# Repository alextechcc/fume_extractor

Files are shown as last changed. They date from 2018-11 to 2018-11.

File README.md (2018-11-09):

# Fume Extractor
A 3d printable fume extractor with a 555 PWM fan controller made in KiCad

- Currently I use a more powerful fan without PWM control, and have used the PWM signal to dim a 10W led driver

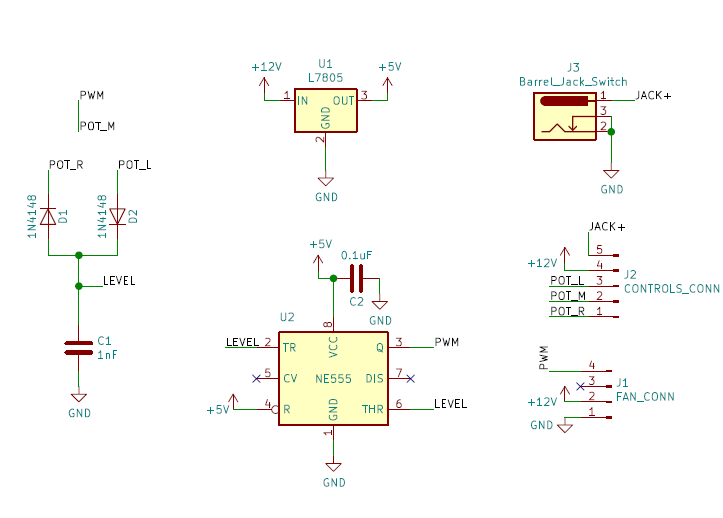
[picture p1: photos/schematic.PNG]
Board

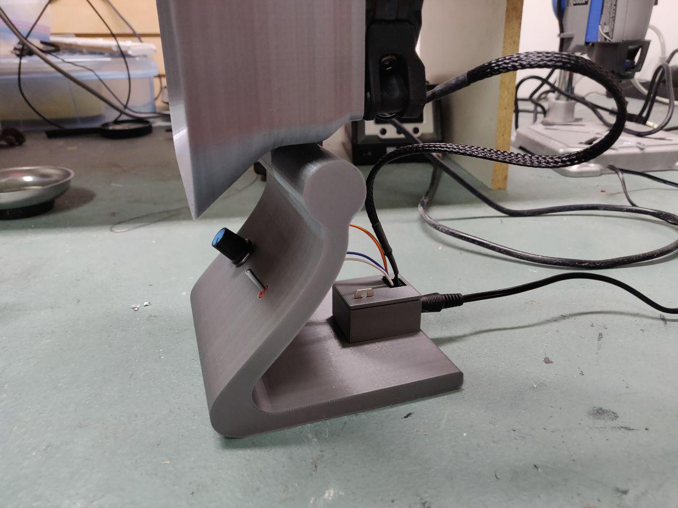
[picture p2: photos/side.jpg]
Side

# Sources
- [Solder Fume Extractor 120 mm by koensmelt](https://www.thingiverse.com/thing:1436781)
- [Customizable Fan Grill Cover by mightynozzle](https://www.thingiverse.com/thing:2802474)

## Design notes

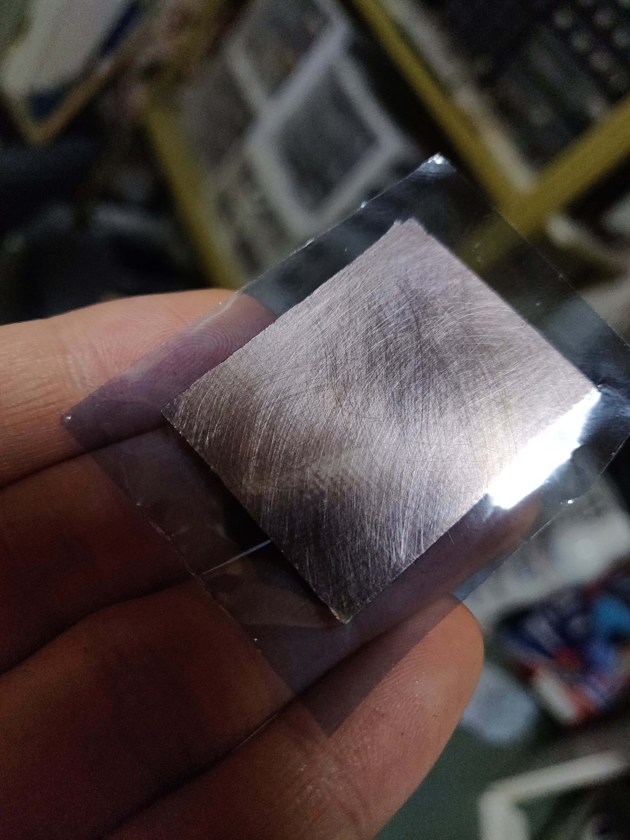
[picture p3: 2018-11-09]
photos/laminated.jpg

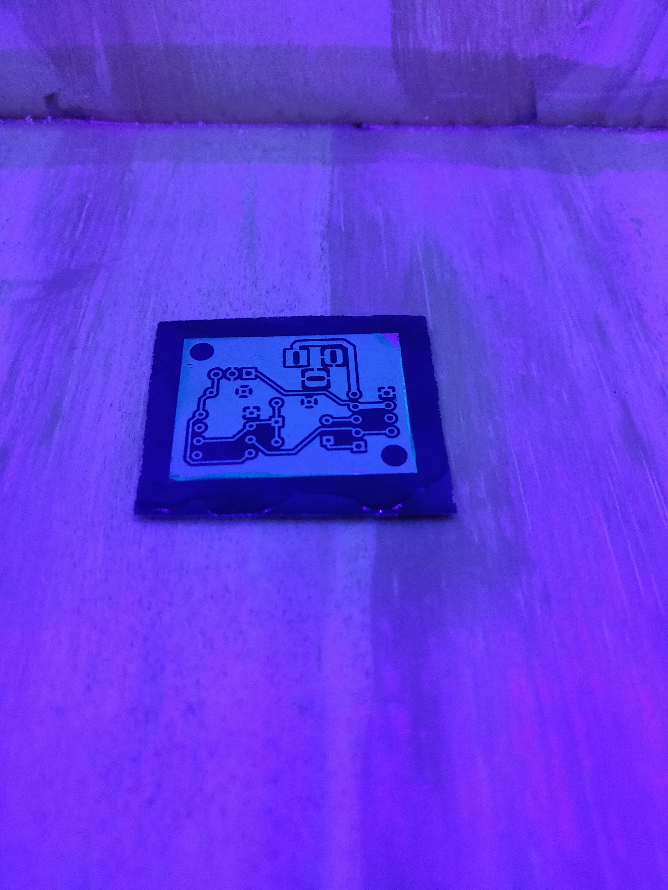
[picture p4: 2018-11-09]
photos/exposing.jpg

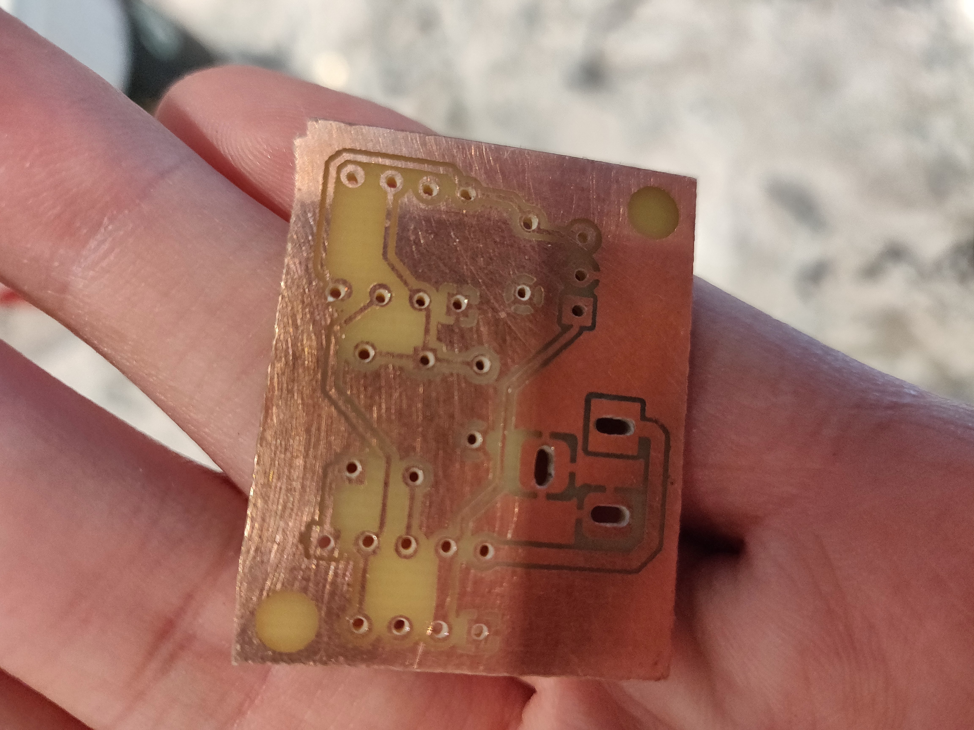
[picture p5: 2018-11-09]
photos/etched_drilled.jpg

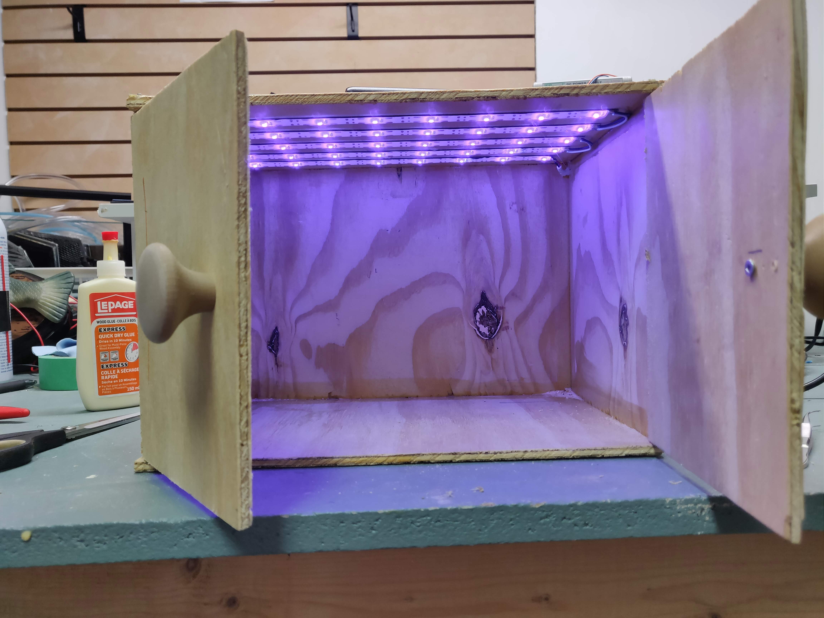
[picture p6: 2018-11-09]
photos/expose_box.jpg

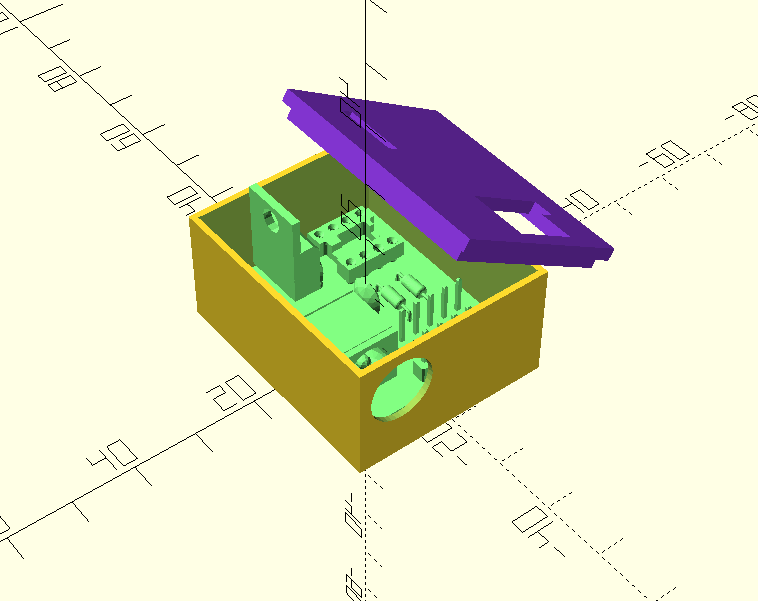
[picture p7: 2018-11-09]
photos/openscad.PNG

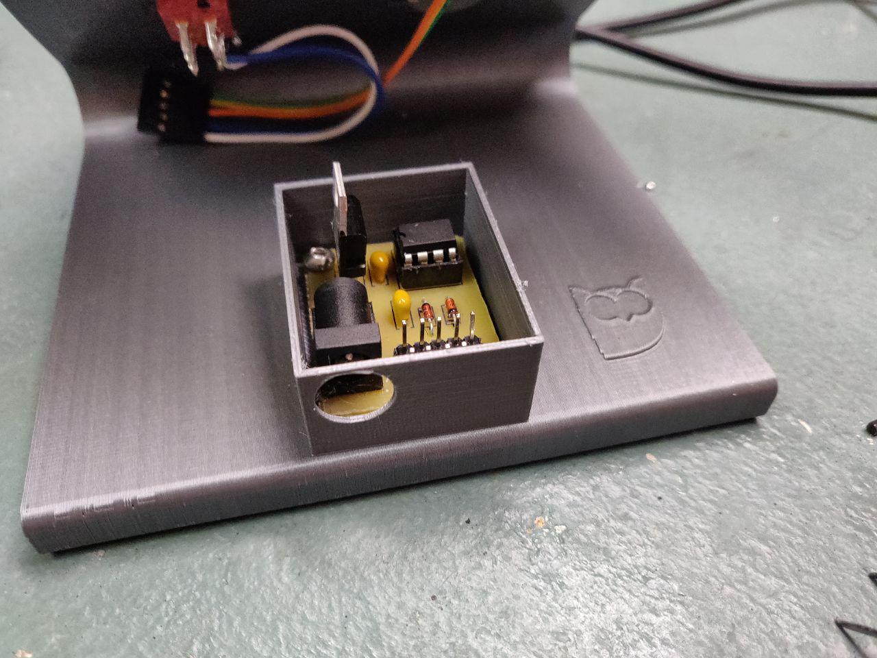
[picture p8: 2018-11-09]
photos/attached.jpg

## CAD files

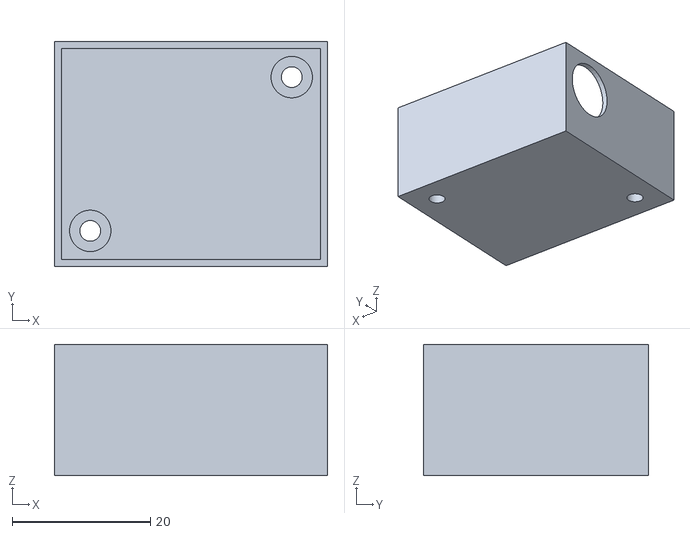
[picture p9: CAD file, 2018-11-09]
exports/case.stl
39.6 x 32.6 x 19.0

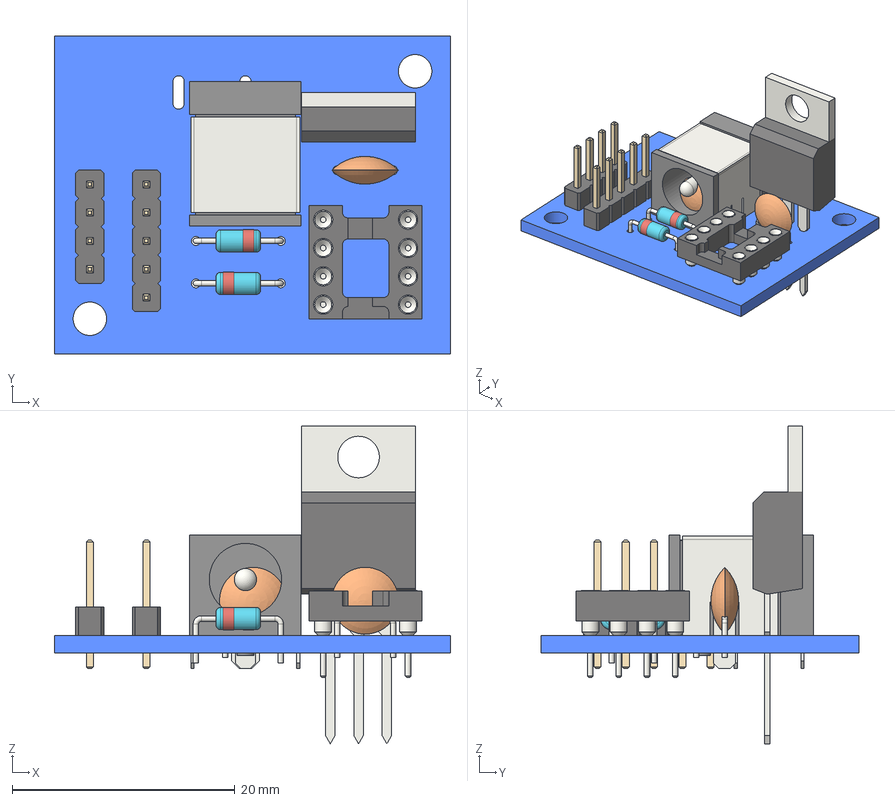
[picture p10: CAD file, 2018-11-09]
freecad/fume_extractor_pcb3.step
35.6 x 28.6 x 28.5 mm

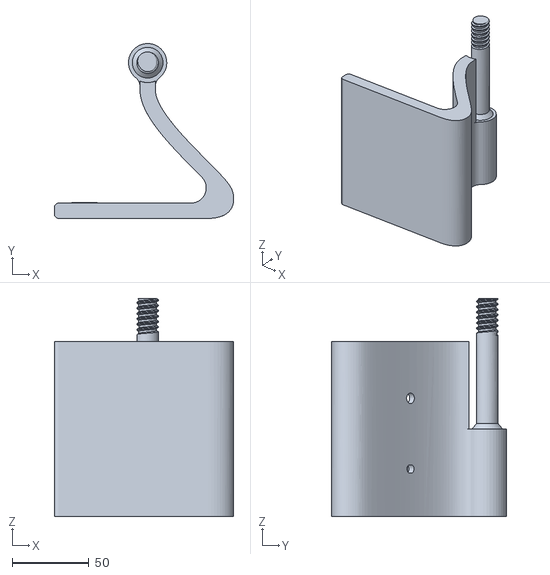
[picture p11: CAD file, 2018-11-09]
models/base_mod.stl
116.9 x 113.9 x 142.0

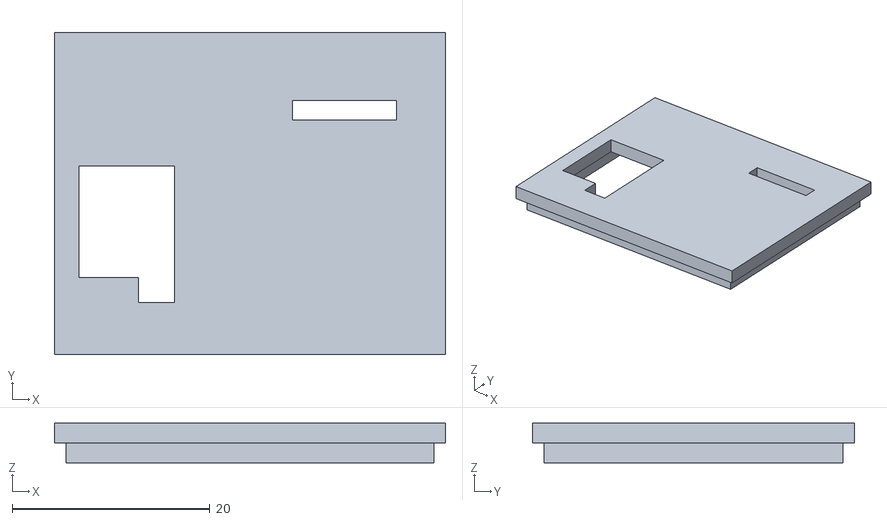
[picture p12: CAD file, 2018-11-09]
exports/lid.stl
39.6 x 32.6 x 4.00

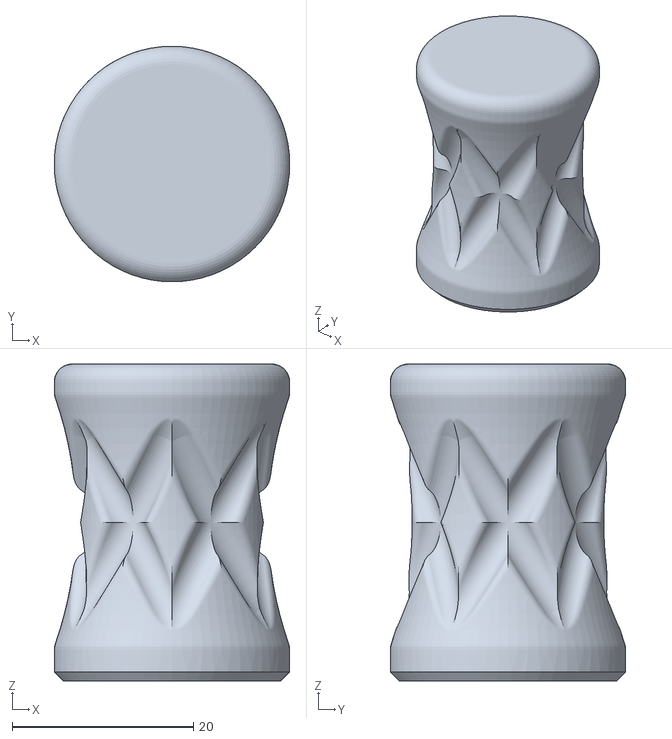
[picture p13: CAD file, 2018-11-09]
models/fume_extractor_knob.STL
26.0 x 26.0 x 35.0

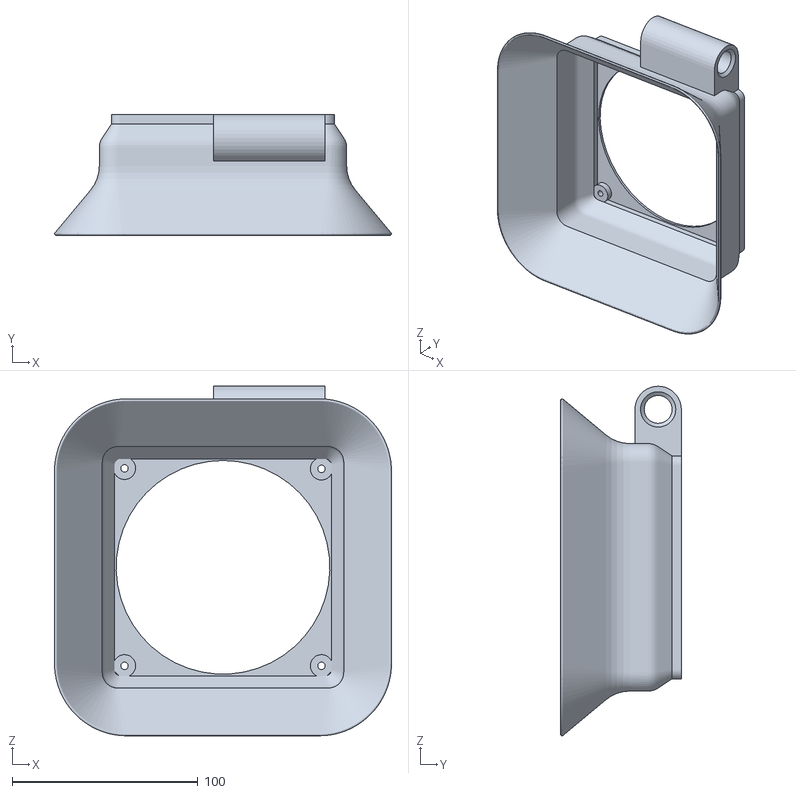
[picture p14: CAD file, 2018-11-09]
models/fume_extractor_head.STL
181.4 x 65.0 x 188.2

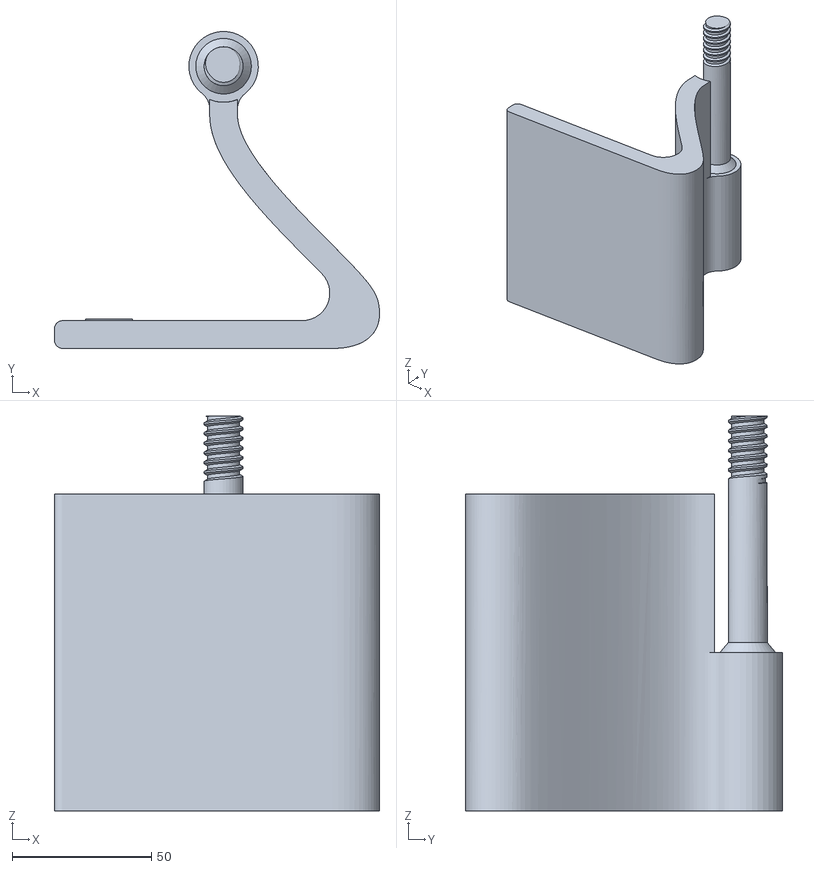
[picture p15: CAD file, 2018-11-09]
models/fume_extractor_foot.STL
116.9 x 113.9 x 142.0

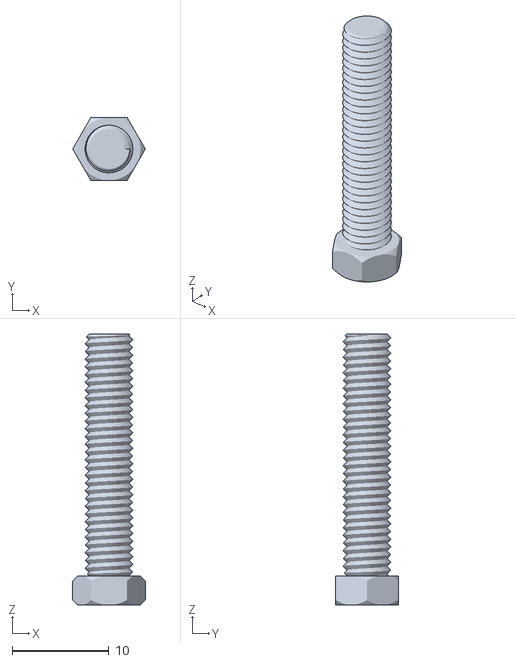
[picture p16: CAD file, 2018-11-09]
models/Nut_Job.stl
7.51 x 6.50 x 28.0

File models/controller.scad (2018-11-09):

use <../../util.scad>

connector_r = 7;
thickness = 2;

header_w = 12.74;
header_d = 2.55;

fanc_w = 13.62;
fanc_h = 8;

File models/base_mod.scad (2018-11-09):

pot_hole_r = 6.9 / 2;
pot_hole_h = 5.4;

off = 23;

pot_w = 20;
pot_h = 30;
pot_d = 9.1;

height = 117 - 3;

switch_h_r = 6.24 / 2;
switch_h_d = 6.2;
switch_h_w = 5.40;

switch_b_w = 11.55;
switch_b_h = 13.20;
switch_b_d = 9;

intersection() {
    difference() {
        import("fume_extractor_foot.STL", convexity=5);

        translate([82.5,48,height/2])
        rotate([-43,90,0])
        union() {
            // Pot
            translate([-off,0,0])
            union() {
                cylinder(r=pot_hole_r, h=pot_hole_h, $fn=25);
                translate([0,6,-4])
                cube([pot_w,pot_h,pot_d],center=true);
            }

            // Switch
            translate([off,0,2.2])
            union() {
                intersection() {
                    cube([switch_h_w, 20, switch_h_d], center=true);
                    cylinder(r=switch_h_r, h=switch_h_d, center=true, $fn=30);
                }
                translate([0,0,-6.5])
                cube([switch_b_w, switch_b_h, switch_b_d], center=true);
            }
        }
    }

    /*
    // isolate pot
    rotate([0,0,30])
    translate([74,-13,68])
    cube([50,40,25]);

    // Isolate switch
    rotate([0,0,30])
    translate([69,-10,27])
    cube([50,20,14]);
    */
}

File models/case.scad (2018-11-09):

use <util.scad>

screw_p = [14.60, 11.14];
header_1_w = 6.02;
header_2_w = 3.68;
header_1_h = 11.3;
header_2_h = 13.84;
header_1_p = [-17.31, 2.8 - header_1_h/2];
header_2_p = [-11.3, 2.8 - header_2_h/2];

regulator_p = [9.55, 8.43];
regulator_w = 10.5;
regulator_h = 2;


screw_r = 3/2;
screw_h = 5;

thickness = 2;
space = 2;
tolerance = 0.3;

insert_d = 6;
insert_r = 4.8 / 2;

board_w = 35.56;
board_d = 28.57;
board_t = 1.58;

jack_p = [-board_w/2 - 4, 9.14, 12];
jack_r = 10.5 / 2;

case_w = board_w + thickness + space;
case_d = board_d + thickness + space;
case_h = 19;


f = 0.01;

explode = 8;

module board() {
    color([0.5,1,0.5])
    tz(1.6 + 2.4 + board_t)
        import("../exports/pcb_mesh.stl", convexity = 5);
}

module mounts() {
    mirror_duplicate([1,1,0])
    translate(screw_p)
        children(0);
}

module case() {
    difference() {
        union() {
            difference() {
                box([case_w, case_d, case_h]);
                tz(thickness)
                    box([case_w-thickness, case_d - thickness, case_h - thickness + f]);
            }
            tz(thickness) mounts() cylinder(r=screw_r*2, h=2, $fn=50);
        }
        tz(-f) mounts() cylinder(r=screw_r, h=screw_h, $fn=50);
        translate(jack_p) ry(90) cylinder(r=jack_r, h=5, $fn=40);
    }
    rx(explode*4) tz(case_h + explode) color([0.5,0.2,0.8]) children(0);
}

module lid() {
    difference() {
        union() {
            box([case_w,case_d,thickness]);
            tz(-thickness)
                box([case_w-thickness-tolerance,case_d-thickness-tolerance,thickness]);
        }
        tz(-thickness-f)
            box([case_w-thickness*2,case_d-thickness*2,thickness+f]);

        tx(header_1_w/2)
        translate(header_1_p)
            box([header_1_w,header_1_h,30]);

        tx(header_2_w/2)
        translate(header_2_p)
            box([header_2_w,header_2_h,30]);

        translate(regulator_p)
            box([regulator_w,regulator_h,30]);
    }
}

board();

case() lid();
//case();
//lid();

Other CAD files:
models/Nut_Job.scad
models/util.scad

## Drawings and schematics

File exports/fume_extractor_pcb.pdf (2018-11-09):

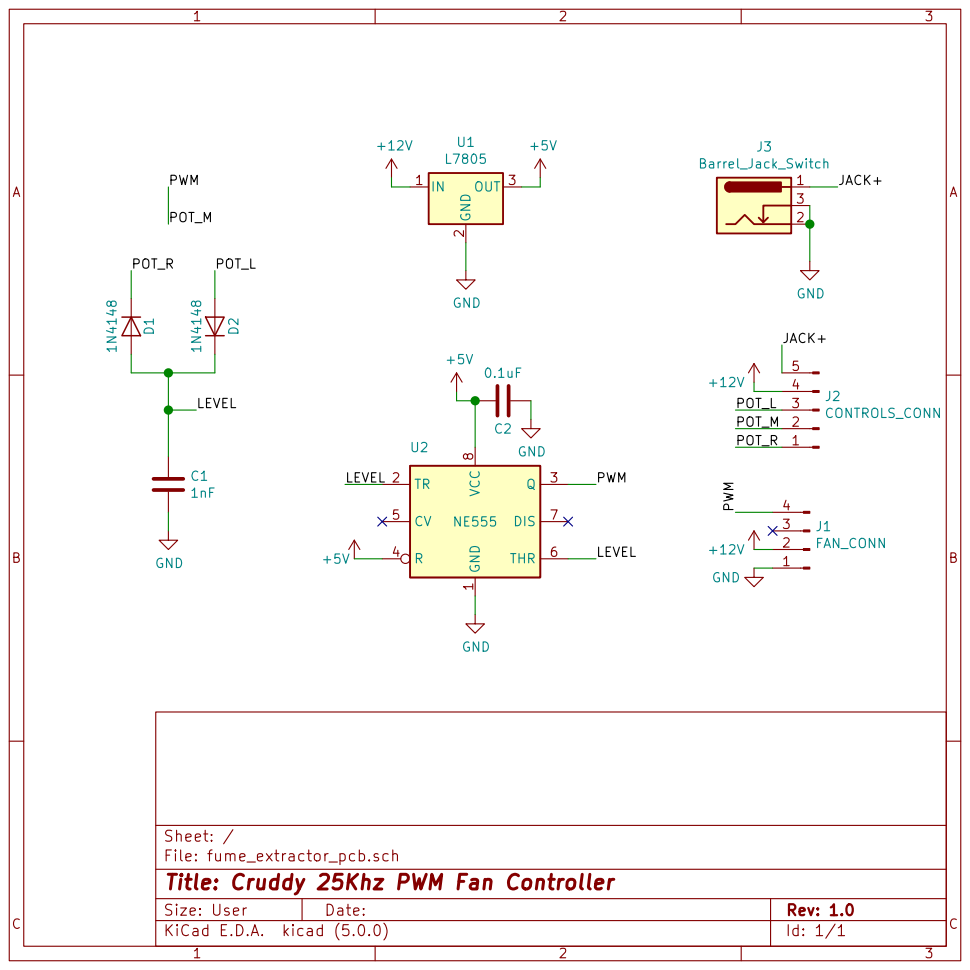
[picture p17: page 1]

Id: 1/1 Title: Cruddy 25Khz PWM Fan Controller

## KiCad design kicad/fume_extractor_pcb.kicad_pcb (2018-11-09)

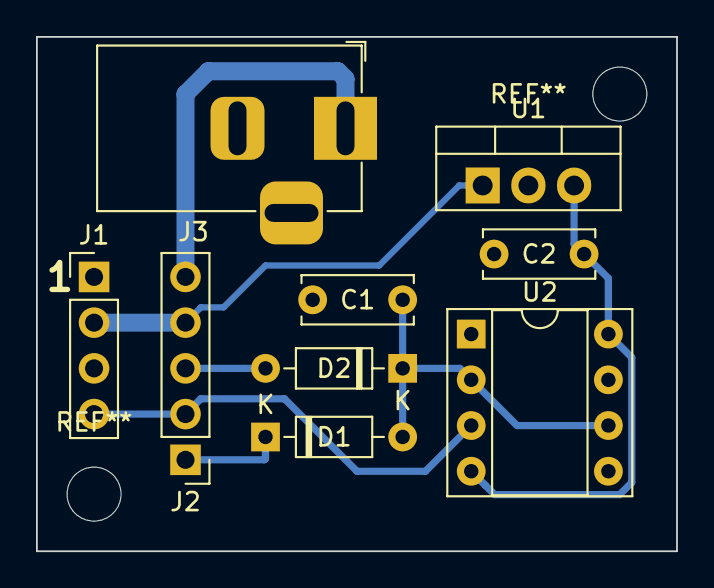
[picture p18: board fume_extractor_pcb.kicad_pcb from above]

Board: 2 copper layers, 35.6 x 28.6 mm, 9 parts (0 on the bottom side), 8 nets.

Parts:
C1: 1nF; C_Disc_D6.0mm_W2.5mm_P5.00mm
C2: 0.1uF; C_Disc_D6.0mm_W2.5mm_P5.00mm
D1, D2: 1N4148; D_DO-35_SOD27_P7.62mm_Horizontal
J1: FAN_CONN; PinHeader_1x04_P2.54mm_Vertical
J2: CONTROLS_CONN; PinHeader_1x05_P2.54mm_Vertical
J3: Barrel_Jack_Switch; BarrelJack_Horizontal
U1: L7805; TO-220-3_Vertical
U2: NE555; DIP-8_W7.62mm_Socket

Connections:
+5V: C2.2, U1.3, U2.4, U2.8
+12V: J1.2, J2.4, U1.1
/JACK+: J2.5, J3.1
/LEVEL: C1.1, D1.2, D2.1, U2.2, U2.6
/POT_L: D2.2, J2.3
/POT_M: J1.4, J2.2, U2.3
/POT_R: D1.1, J2.1
GND: C1.2, C2.1, J1.1, J3.2, J3.3, U1.2, U2.1
